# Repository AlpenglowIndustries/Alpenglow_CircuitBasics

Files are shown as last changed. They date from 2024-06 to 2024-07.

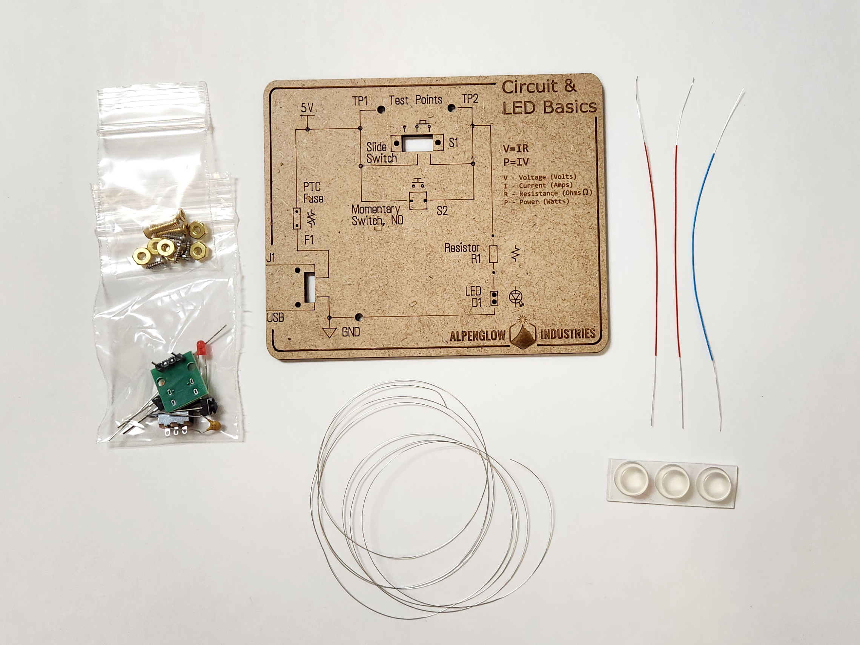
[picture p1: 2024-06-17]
LEDBasics/LEDBasicsKit.jpg

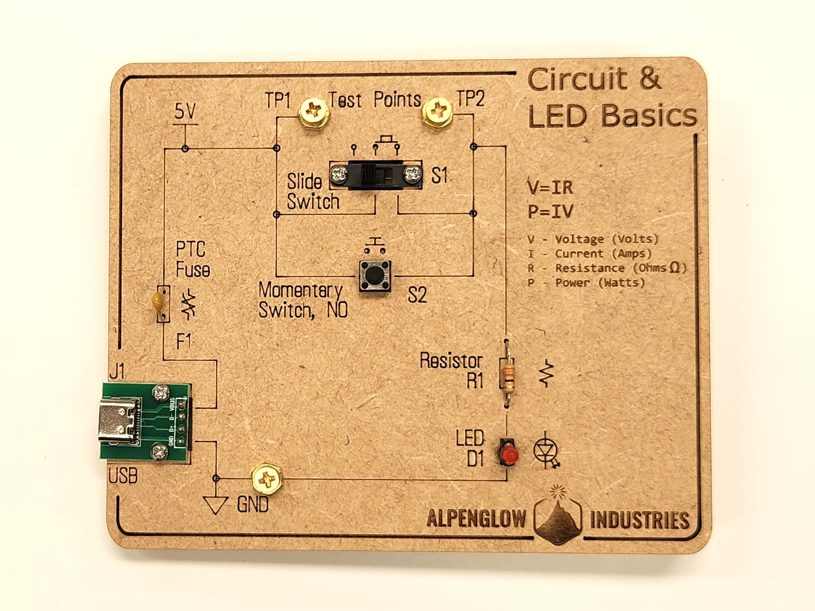
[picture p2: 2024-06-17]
LEDBasics/LEDBasicsFront.jpg

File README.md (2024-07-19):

# Alpenglow_CircuitBasics

Click the LED Basics folder above for files and to see our first Circuit Basics kit!

Here you will find files related to the Circuit Basics series of laser-cut wood breadboards we are developing!  The goal of this project is to share kits that help a person learn about electronics, without needing to know how to solder or have soldering equipment.  It's a throwback to OG "Breadboards" which were made of wood, used nails as common junction points, and connected components with wire wrapped around their legs and these nails.  In our case, we're using laser-cut MDF as our breadboard and screws as tie points. Each board has a circuit engraved on it, where components are laid our like a schematic with the schematic symbols next to them.  Working with actual electronic components helps build familiarity, and having a clear spot to place each component removes some confusion that beginners can experience when first using the grid-style plastic solderless breadboards.  These also help teach schematic reading and multimeter use.

We are open-sourcing these files in our never-ending quest to reduce gatekeeping and make electronics more accessible.  This way, anyone with access to a laser cutter can create these breadboards themselves, and makerspaces and educational institutions can both make and use them as teaching tools.  We also will sell ready-made kits at alpenglowindustries.com, and we offer discounts for volume orders.

This project was initially launched thanks to funding from a Diversity, Equity, and Inclusion grant from the City of San Luis Obispo.  Thanks for believing in and supporting our mission!

06/17/2024: We have just created this repo and are in the process of updating and adding materials & files

More Resources:
* [Alpenglow Storefront](https://www.alpenglowindustries.com/store)
* [Basic Electronics Cheat Sheet (short)](https://cdn.shopify.com/s/files/1/0608/6698/6193/files/Basic_Electronics_Workshop_Cheat_Sheet.pdf?v=1716591500)
* [Basic Electronics Crash Course (long)](https://cdn.shopify.com/s/files/1/0608/6698/6193/files/Basic_Electronics_Workshop_Crash_Course.pdf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)
* [Other Tutorials](https://www.alpenglowindustries.com/pages/tutorials-home-page)

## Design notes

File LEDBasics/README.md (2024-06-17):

# LED Basics

[Instructions](https://www.alpenglowindustries.com/pages/instructions-home-page) for assembling & using this breadboard

LEDBasicsFront

LEDBasicsBack

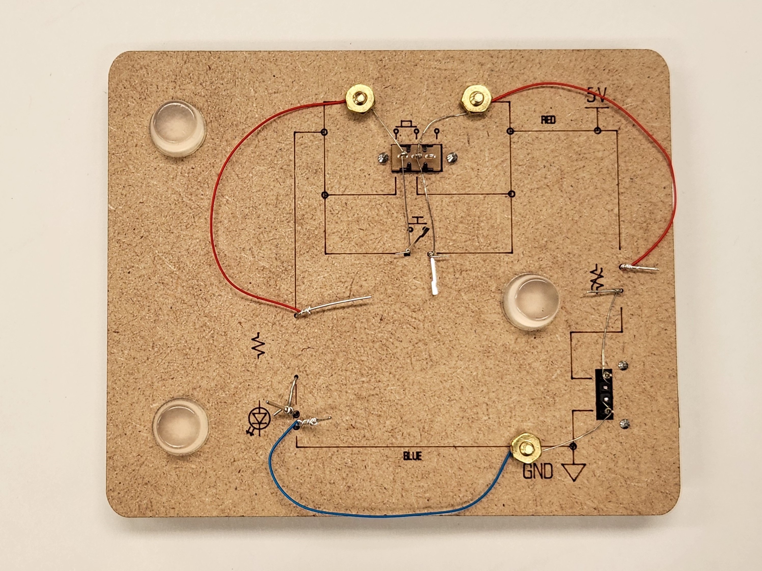
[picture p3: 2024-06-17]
LEDBasics/LEDBasicsBack.jpg

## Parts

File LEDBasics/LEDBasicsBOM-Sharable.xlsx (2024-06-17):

Part Type | Description | Qty | UOM | Manufacturer | Manufacturer P/N | Supplier | Supplier P/N | Link | Mouser Cross?
PCB | USB-C connector breakout board, assembled | 1 | ea | Pracitcal Tool 47 Store |  | AliExpress | 3256805658604280 | https://www.aliexpress.us/item/3256805658604289.html | None
Fuse | PTC fuse | 1 | ea | Littelfuse Inc. | RXEF010S | Digi-Key | RXEF010SHF-ND | https://www.digikey.com/en/products/detail/littelfuse-inc/RXEF010S/5016026
Switch | Momentary switch NO, 6mm x 6mm, through-hole, 2 pin, 10mm long leads | 1 | ea | excellence electronic |  | AliExpress | 3256803268629026 | https://www.aliexpress.us/item/3256803268629026.html | None
Slide Switch | Slide switch, SPDT, front panel vertical mount, 10.5 x 5.77mm, 14mm spaced mounting holes for #2 or M2 screws, solder lug terminations | 1 | ea | Chanzon | SS12F15 | Amazon | B09R3Y6MMN | https://www.amazon.com/gp/product/B09R3Y6MMN | None
Hardware | 4-40 x 1/2" long flat-head phillips machine screws, brass | 3 | ea |  |  | McMaster-Carr | 92480A110 | https://www.mcmaster.com/92480A110/
Hardware | 4-40 nuts, brass | 3 | ea |  |  | McMaster-Carr | 92671A005 | https://www.mcmaster.com/92671A005/
Resistor | 330 ohm resistor, 5%, axial leads, through-hole | 1 | ea |  |  | Amazon | B07HDFFN81 | https://www.amazon.com/EDGELEC-Resistor-Tolerance-Resistance-Optional/dp/B07HDFFN81
LED | 5mm LED, red, through-hole | 1 | ea |  |  | Amazon | B01C3ZZT2I | https://www.amazon.com/Diffused-Lighting-Electronics-Components-Emitting/dp/B01C3ZZT2I
Hardware | #2 x 1/4" long pan-head phillips wood or sheet metal screws | 4 | ea |  |  | Amazon | B07PDC3F85 | https://www.amazon.com/gp/product/B07PDC3F85
Wire | 30 AWG solid core wire-wrap wire, red insulated, 5" long, stripped 1" each end, 2 per kit | 0.04 | pack of 50 | Jonard Tools | 30-R-50-030 | Jonard Tools | 30-R-50-030 |  | Non-stocked
Wire | 30 AWG solid core wire-wrap wire, blue insulated, 5" long, stripped 1" each end, 1 per kit | 0.02 | pack of 50 | Jonard Tools | 30-B-50-030 | Jonard Tools | 30-B-50-030 |  | Non-stocked
Wire | 30 AWG solid core wire-wrap wire, bare uninsulated, 18" long, tinned | 0.015 | spool of 100 ft | Remington Industries | 30TCW | Remington Industries | 30TCW | https://www.remingtonindustries.com/uninsulated-wire/tinned-copper-wire/tinned-copper-wire-buss-wire-30-awg-silver-7-spool-sizes/ | None
Connector | Socket for wire-wrap, 0.1" pitch, 10mm long leads, 2 pos (can be a longer strip cut down) | 1 | ea | RTLECS Engineering Solutions Store |  | AliExpress | 2255799995434827 | https://www.aliexpress.us/item/2255799995434827.html | None
Breadboard | Custom laser-engraved "breadboard" wood base for circuit construction | 1 | ea |  |  | Alpenglow Industries | CBK-001 |  | None
Notes: | Red and blue insulated wire-wrap wires are helpful, but can do with only uninsulated spools and have participants cut off pieces.
 | Uninsulated wire is required for the kit.
Group Supplies
LED | Assorted colors of 5mm LEDs, including some with Vf ~3.0V (blue, white). The above LED part number is for a kit of 100 which is sufficient for the class. | 100 | per class
Glue | CA glue, thick or gel | 1 | per student
Cutters | for 30 AWG wire-wrap wires, good condition, jaws should meet and cut well at the tip | 1 | per student
Pliers | Serrated jaws, can be the plier end of wire strippers | 1 | per student
Screwdrivers | Small, phillips #1 | 1 | per student
Multimeter | Auto-ranging preferred, students can BYO, alligator and probe-style tips both helpful | 1 | per student
Wrench | 1/4" wrench for nuts | 5 | per class
Wrench | (optional) 3D printed socket for hand-tightening 1/4" nuts, see Alpenglow_CircuitBasics github repo | 1 | per student
Materials preparation labor prior to class:
 | Soldering through-hole headers onto USB board
 | Laser cutting the breadboards
 | Kitting and packaging everything
 | Printing handouts

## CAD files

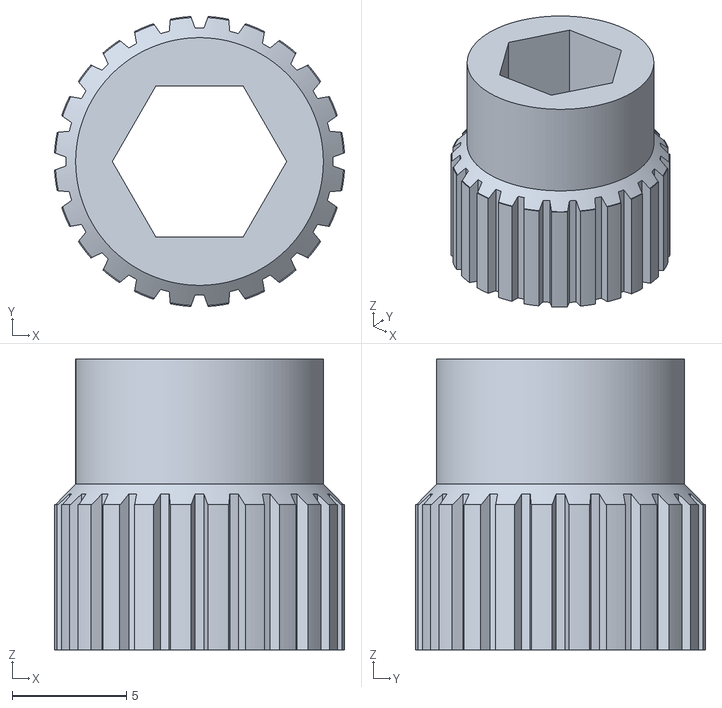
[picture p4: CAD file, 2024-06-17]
LEDBasics/ThumbSocket3DPrint/ThumbSocketv2.stl
12.7 x 12.7 x 12.7

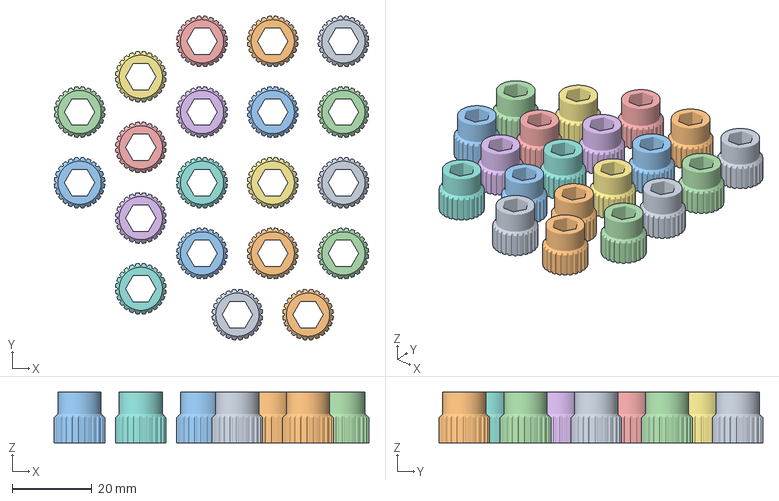
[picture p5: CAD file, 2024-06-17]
LEDBasics/ThumbSocket3DPrint/ThumbSocket.3mf
78.7 x 81.0 x 12.7 mm
ThumbSocketv2.stl x 20

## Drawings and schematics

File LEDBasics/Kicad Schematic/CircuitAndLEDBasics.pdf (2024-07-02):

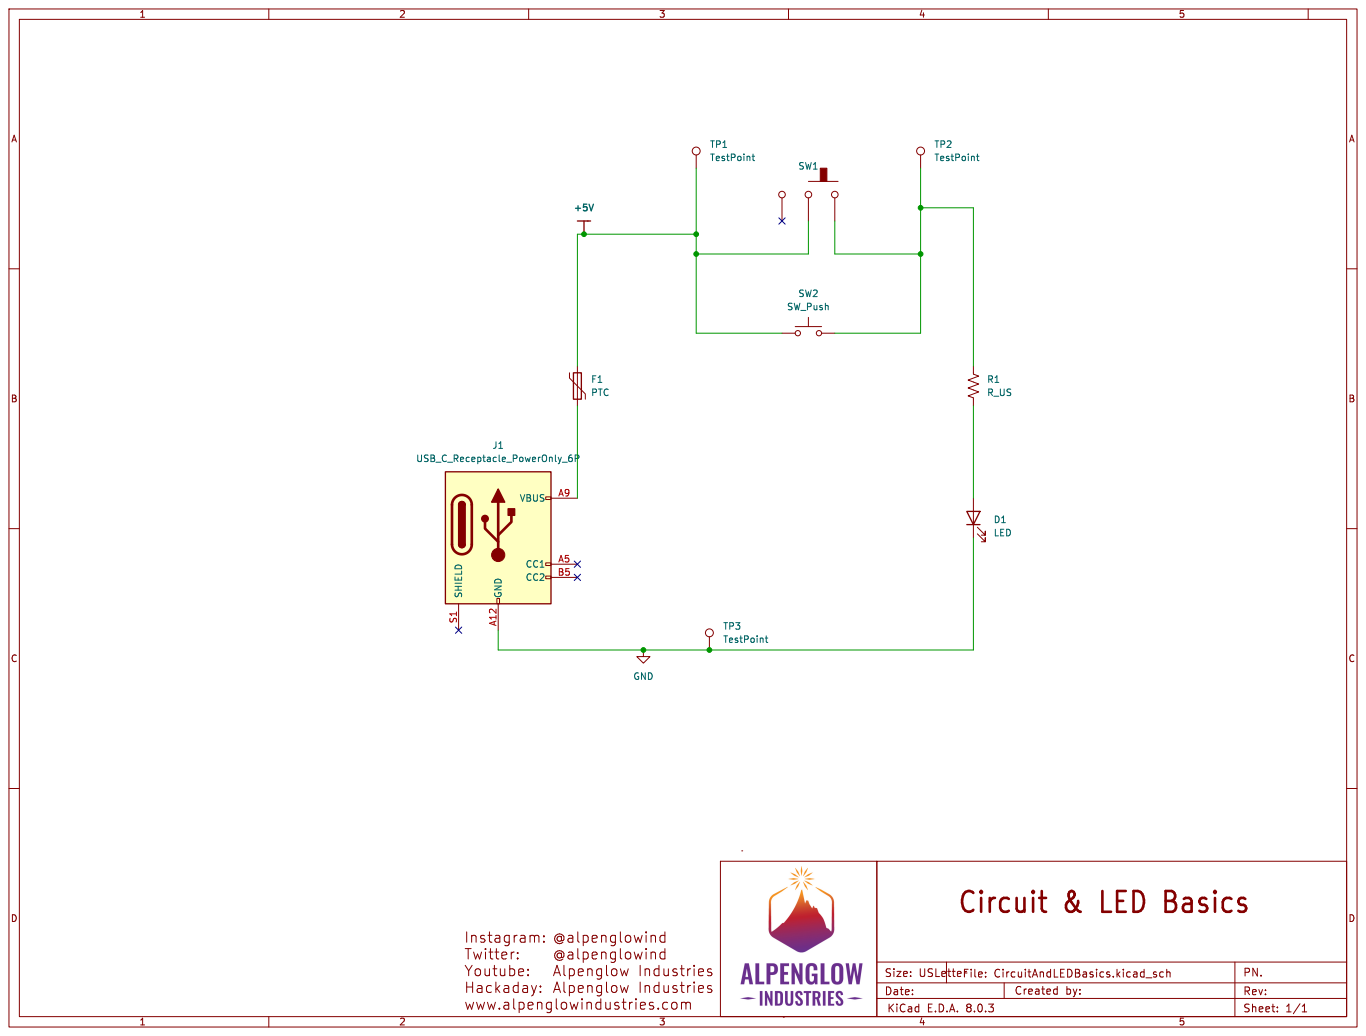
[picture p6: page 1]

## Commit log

2024-07-02 Committed Kicad files
    [CircuitAndLEDBasics.kicad_pcb, CircuitAndLEDBasics.kicad_sch]
2024-07-02 Added alpenglow title block
    [CircuitAndLEDBasics.kicad_sch]
